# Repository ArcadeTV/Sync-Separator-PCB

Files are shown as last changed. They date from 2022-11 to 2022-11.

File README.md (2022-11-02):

# Sync-Separator-PCB
Eagle printed circuit board for VGA or NTSC/PAL CSYNC to H/V

This is a work-in-progress repo. As of today, 2022/10/22 this is a prototype pcb which has been ordered for further testing.

The circuit is based on a EL1883 which splits the input of a composite sync signal into horizontal and vertical sync to the output-vga-port. This is useful if you have any hardware that outputs CSYNC only and your display device is not happy with that. For example I designed this for using my Atomiswave arcade mainboard on a VGA CRT monitor which expects both H- and V-Sync to be present to work.

As pointed out by by [maki9000](https://circuit-board.de/forum/index.php/User/20222-maki9000/), the EL1883 performs better when it's powered by 3.3V which is why there is an AMS1117 regulator in the BOM. This is likely to be replaced by either a TPS78233DDCR or TLV70033DDCR in future versions.

### Enclosure
[KEMO G026](https://www.kemo-electronic.de/de/Bauelemente/Geh%C3%A4use/Geschlossen/G026N-Gehaeuse-schwarz-ca-72-x-50-x-28-mm.php)

Both sides need a rectangular cut for the vga connectors. 4 PT-screws 3x5mm needed for pcb mounting inside the case.

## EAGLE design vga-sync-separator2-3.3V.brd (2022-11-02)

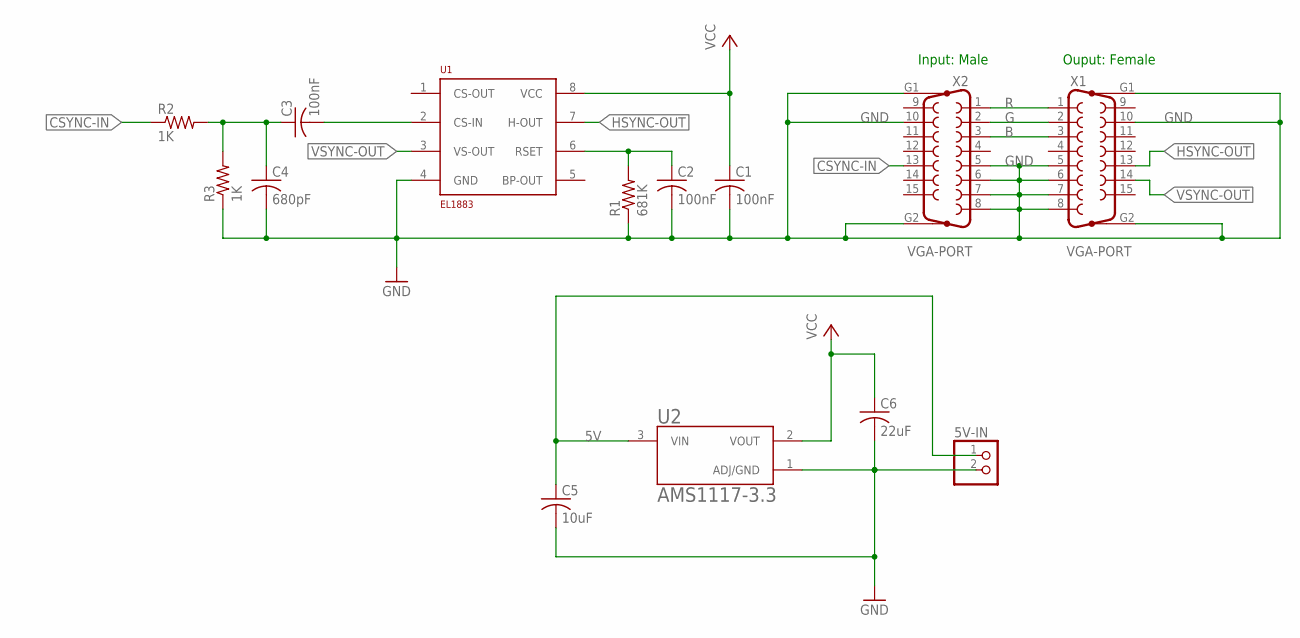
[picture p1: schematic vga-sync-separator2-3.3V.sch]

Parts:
5V-IN: PINHD-1X2; 1X02
C1, C2, C3: 100nF; C0805
C4: 680pF; C0805
C5: 10uF; C0805
C6: 22uF; C0805
R1: 681K; R0805
R2, R3: 1K; R0805
U1: EL1883; SO-8
U2: AMS1117-3.3; SOT229P700X180-4N
X1, X2: VGA-PORT; HD15H

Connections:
5V: 5V-IN.1, C5.1, U2.3 (VIN)
B: X1.3, X2.3
CSYNC-IN: R2.1, X2.13
G: X1.2, X2.2
GND: 5V-IN.2, C1.2, C2.2, C4.2, C5.2, C6.2, R1.1, R3.1, U1.4 (GND), U2.1 (ADJ/GND), X1.5, X1.6, X1.7, X1.8, X1.10, X1.G1, X1.G2, X2.5, X2.6, X2.7, X2.8, X2.10, X2.G1, X2.G2
HSYNC-OUT: U1.7 (H-OUT), X1.13
unnamed: C3.2, U1.2 (CS-IN)
unnamed: C3.1, C4.1, R2.2, R3.2
unnamed: C2.1, R1.2, U1.6 (RSET)
R: X1.1, X2.1
VCC: C1.1, C6.1, U1.8 (VCC), U2.2 (VOUT)
VSYNC-OUT: U1.3 (VS-OUT), X1.14

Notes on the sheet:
Input: Male
Ouput: Female

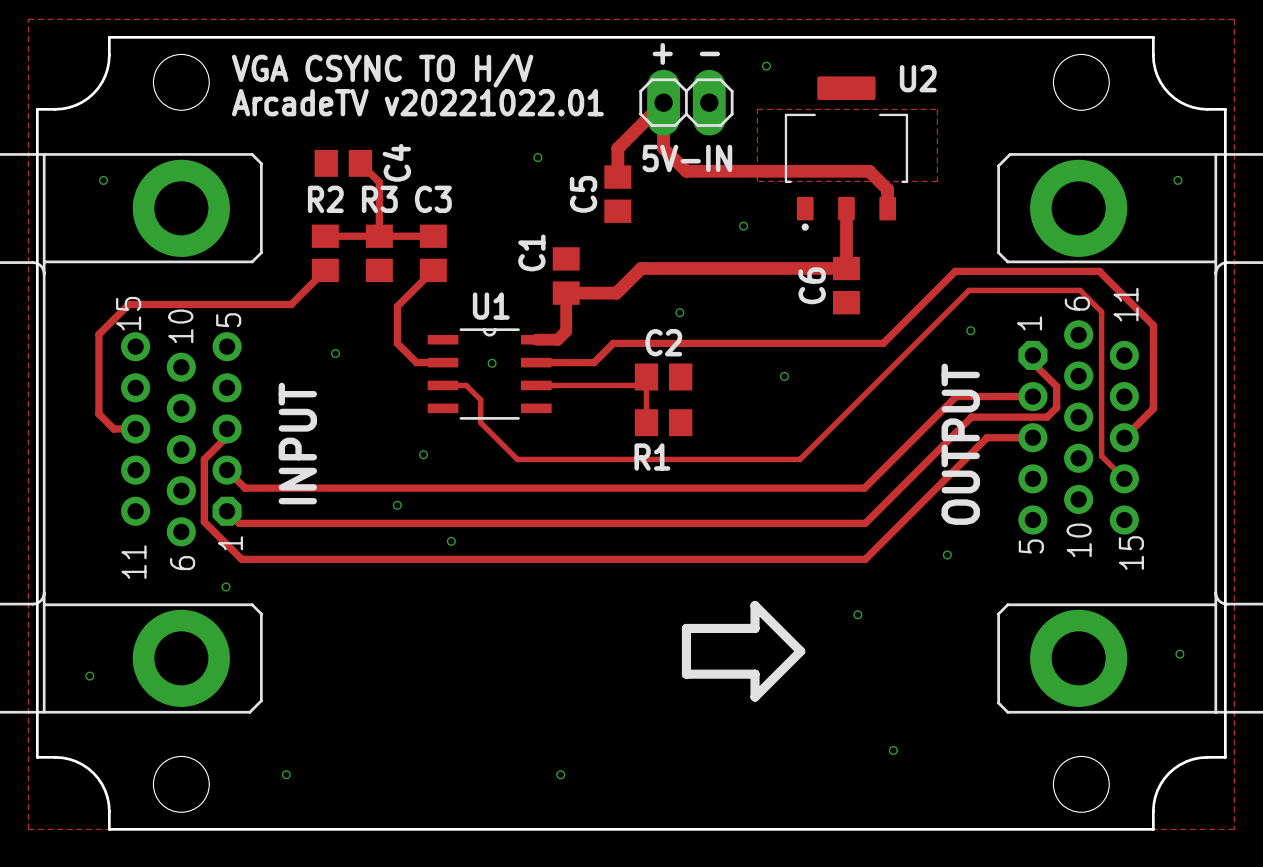
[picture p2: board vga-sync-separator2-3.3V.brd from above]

Board: 2 copper layers, 66.0 x 44.0 mm, 14 parts (0 on the bottom side), 12 nets.
